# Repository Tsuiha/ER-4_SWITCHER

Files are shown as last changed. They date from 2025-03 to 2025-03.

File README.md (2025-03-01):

# ER-4_SWITCHER

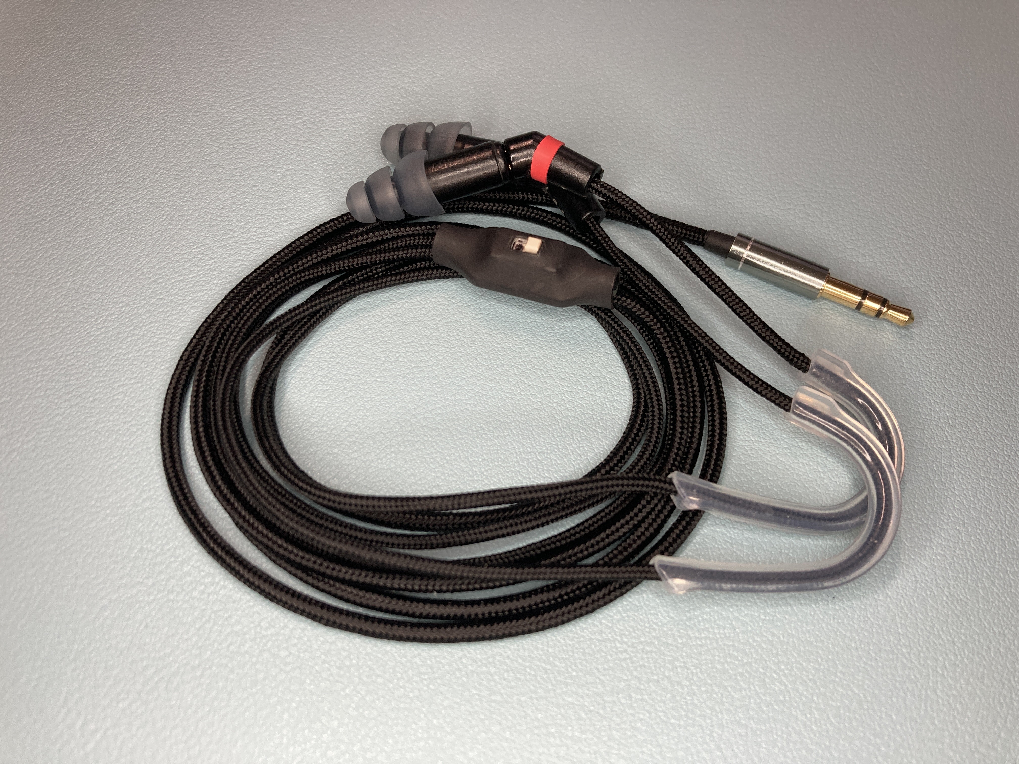
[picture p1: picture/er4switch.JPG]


　「ER-4 SWITCHER」はEtymotic Reserch ER-4S, ER-4Bをリケーブルする際に使用できるネットワーク内蔵機器です。またスイッチを切り替えることでER-4S, ER-4Bの2種類のサウンドを楽しむことができます。  
 　ケーブル一体型の「Yスプリッタ」と、ステレオミニジャック接続用の「I, Uアダプタ」の3種類を製作しました。  
　ER-4筐体に加え、Yスプリッタは単体で、I, UアダプタはネットワークレスのリケーブルとICケーブルを別途用意することで、ER-4S, ER-4Bのリケーブルとして使用することができます。  
　組み立て済みのものは、ER-4Bタイプに切り替えた時に黒点が見えるようマーキングしてあります。入出力の方向性はありません。  

 　リポジトリに基板データと使用パーツが公開されています。 自由にしてください。
  
　[noteでも紹介しています](https://note.com/tsuiha/m/m1b87ad4bef4d)

*Yスプリッタ+リケーブル*

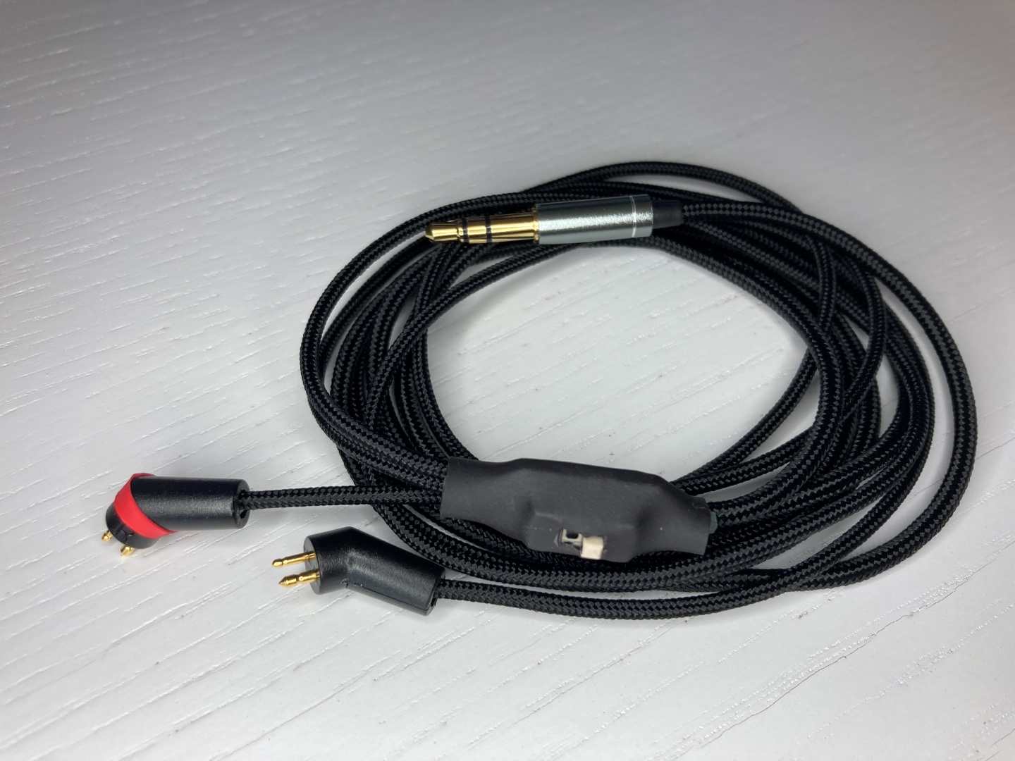
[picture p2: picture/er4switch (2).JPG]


*Iアダプタ*

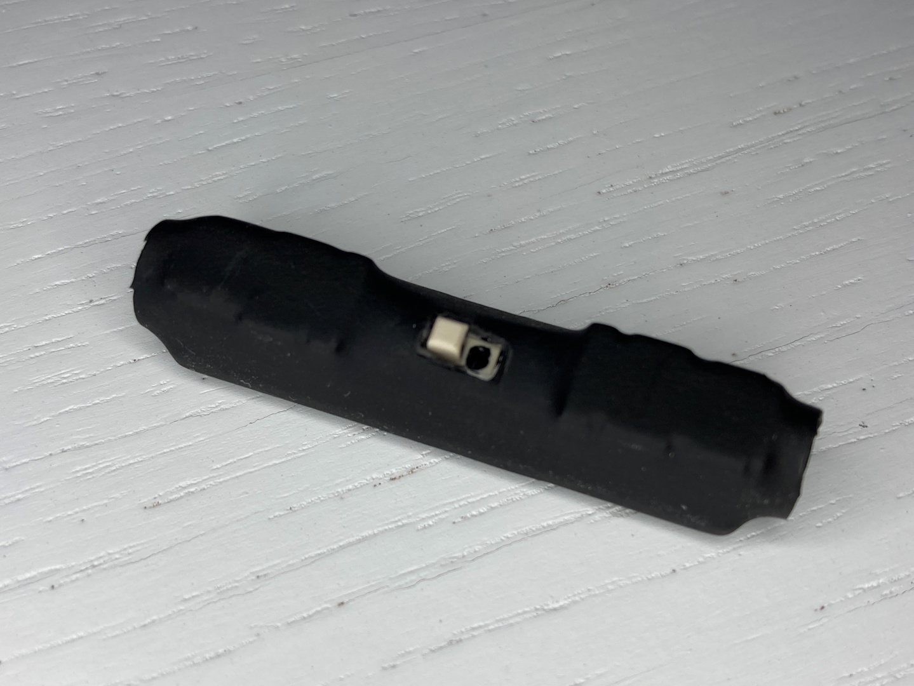
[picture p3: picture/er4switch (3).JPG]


*Uアダプタ*

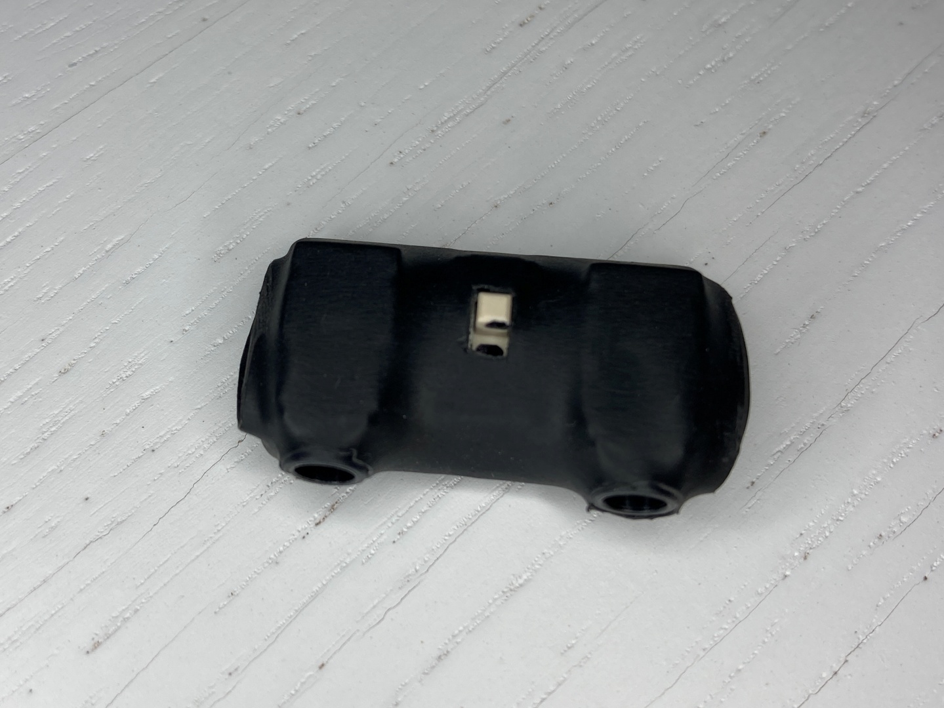
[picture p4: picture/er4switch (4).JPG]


*PCB*





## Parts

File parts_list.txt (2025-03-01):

ステレオジャック (x2/pcs)・・・ST-005-G (秋月電子)

100Ω抵抗 (x4/pcs)・・・YAGEO RT0603BRB07100RL 1608M (Digikey)

220nFコンデンサ (x2/pcs)・・・ルビコン 16MU224MZ22012 2012M (Digikey)

切り替えスイッチ (x1/pcs)・・・ニデック CMS-2212B

熱収縮チューブ

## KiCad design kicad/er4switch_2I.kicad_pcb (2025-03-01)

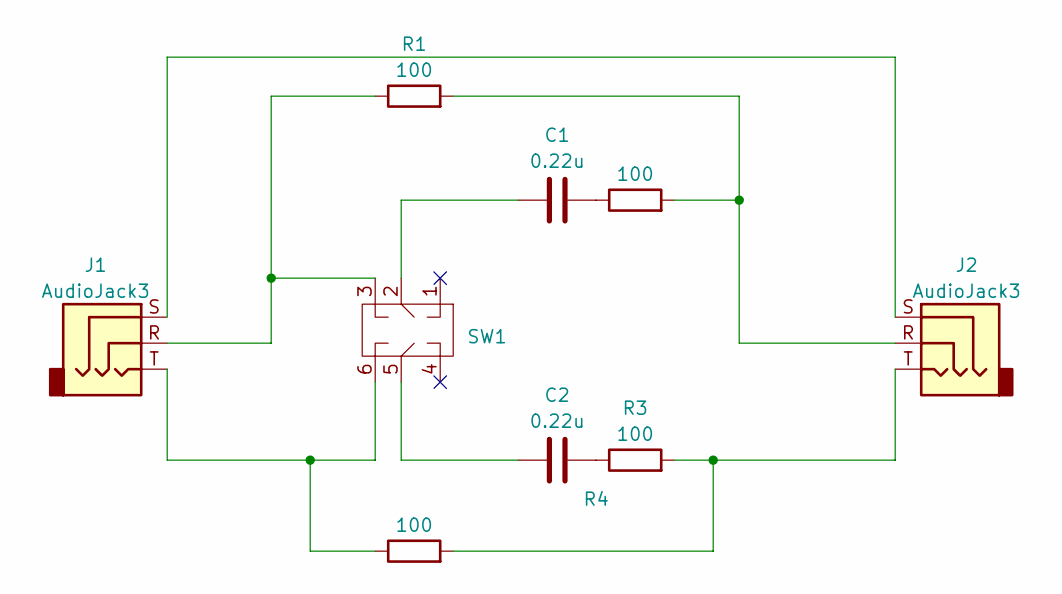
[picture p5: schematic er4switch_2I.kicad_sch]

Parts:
C1, C2: 0.22u; C_0805_2012Metric_Pad1.18x1.45mm_HandSolder
J1, J2: AudioJack3; Jack_3.5mm_Switronic_ST-005-G_horizontal
R1, R2, R3, R4: 100; R_0603_1608Metric_Pad0.98x0.95mm_HandSolder
SW1: CMS-2202TB

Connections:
unnamed: C1.1, SW1.2
unnamed: C1.2, R2.1
unnamed: C2.1, SW1.5
unnamed: C2.2, R3.1
unnamed: J1.R, R1.1, SW1.3
unnamed: J1.S, J2.S
unnamed: J1.T, R4.1, SW1.6
unnamed: J2.R, R1.2, R2.2
unnamed: J2.T, R3.2, R4.2

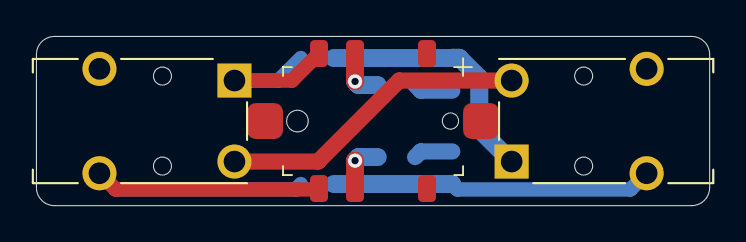
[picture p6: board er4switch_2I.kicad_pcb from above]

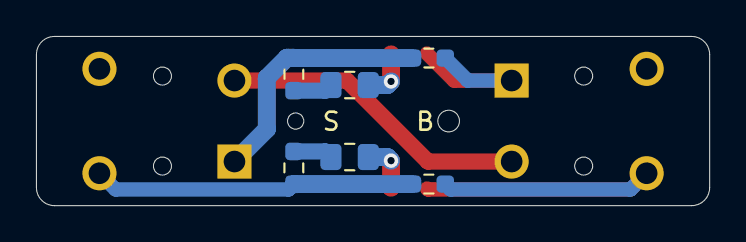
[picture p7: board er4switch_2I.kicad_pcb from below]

Board: 2 copper layers, 37.4 x 9.4 mm, 9 parts (6 on the bottom side), 9 nets.

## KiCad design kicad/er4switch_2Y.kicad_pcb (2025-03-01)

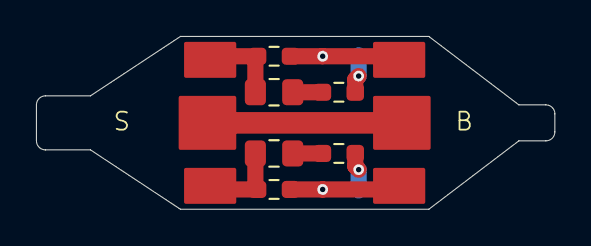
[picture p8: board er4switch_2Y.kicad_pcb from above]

Board: 2 copper layers, 28.8 x 9.6 mm, 7 parts (1 on the bottom side), 8 nets.

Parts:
C1, C2: 0.22u; C_0805_2012Metric_Pad1.18x1.45mm_HandSolder
R1, R2, R3, R4: 100; R_0603_1608Metric_Pad0.98x0.95mm_HandSolder
SW1: CMS-2202TB_nopole

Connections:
unnamed: C1.1, R2.2
unnamed: C1.2, R1.2
unnamed: C2.1, R3.2
unnamed: C2.2, R4.2
unnamed: R1.1, SW1.5
unnamed: R4.1, SW1.2
unnamed: R2.1, SW1.6
unnamed: R3.1, SW1.3
